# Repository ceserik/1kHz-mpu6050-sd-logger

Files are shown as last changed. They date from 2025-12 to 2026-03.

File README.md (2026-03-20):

# 1khz logger for mpu6050 accelerometer + gyro, using arduino mini pro

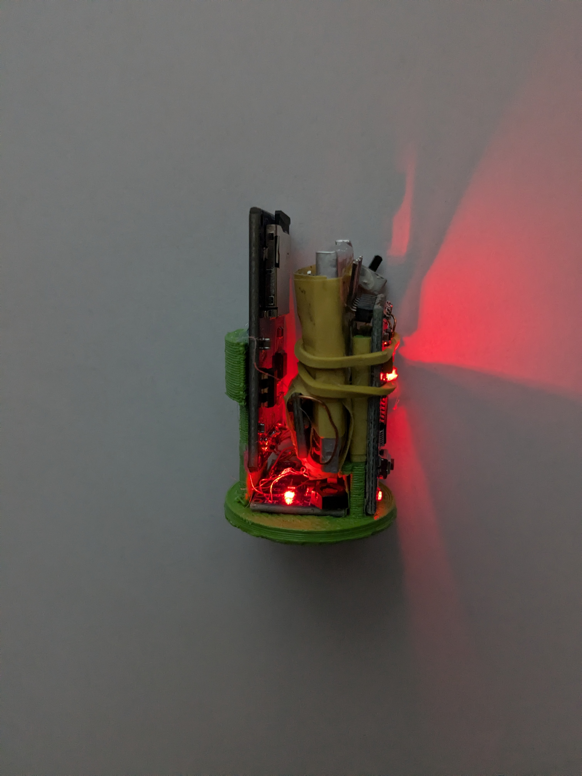
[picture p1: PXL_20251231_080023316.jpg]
Rocket Logger Device


I wrote this to log motion of hobby rocket launch. The code periodically reads FIFO buffer on MPU6050 and logs it to a SD card. Maximum sample rate of accelerometer is 1kHz, so I chose this as logging frequency. The data is stored as binary on sd card and you need to use converter.py to convert it to csv.

## Images

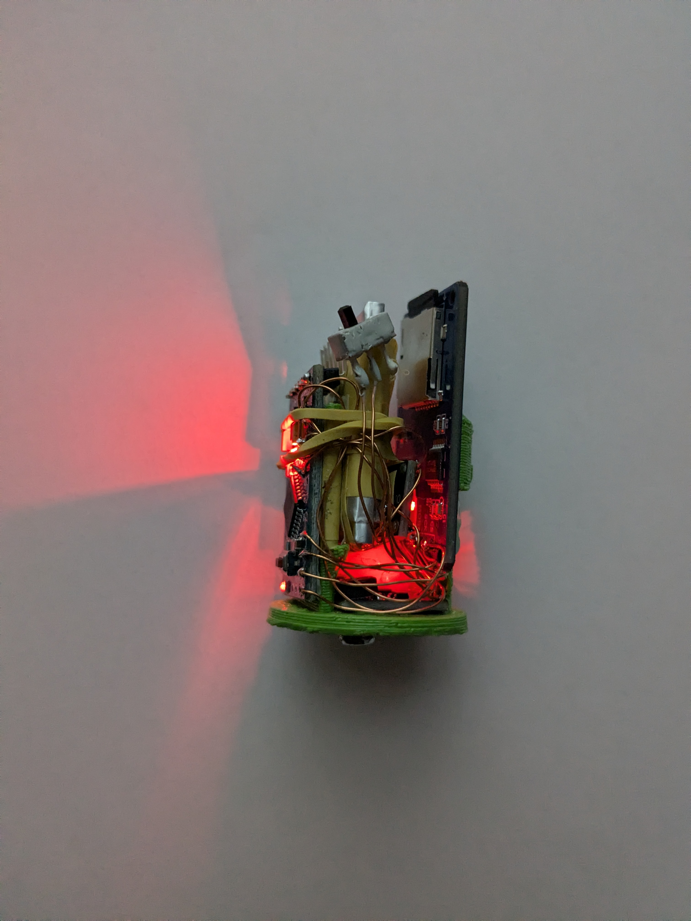
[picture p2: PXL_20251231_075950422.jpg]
Device View 1

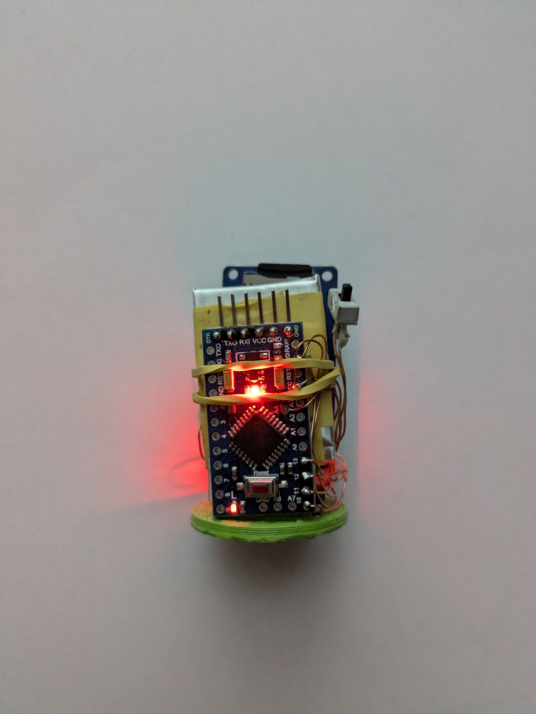
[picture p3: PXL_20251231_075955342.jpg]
Device View 2


## Data Analysis

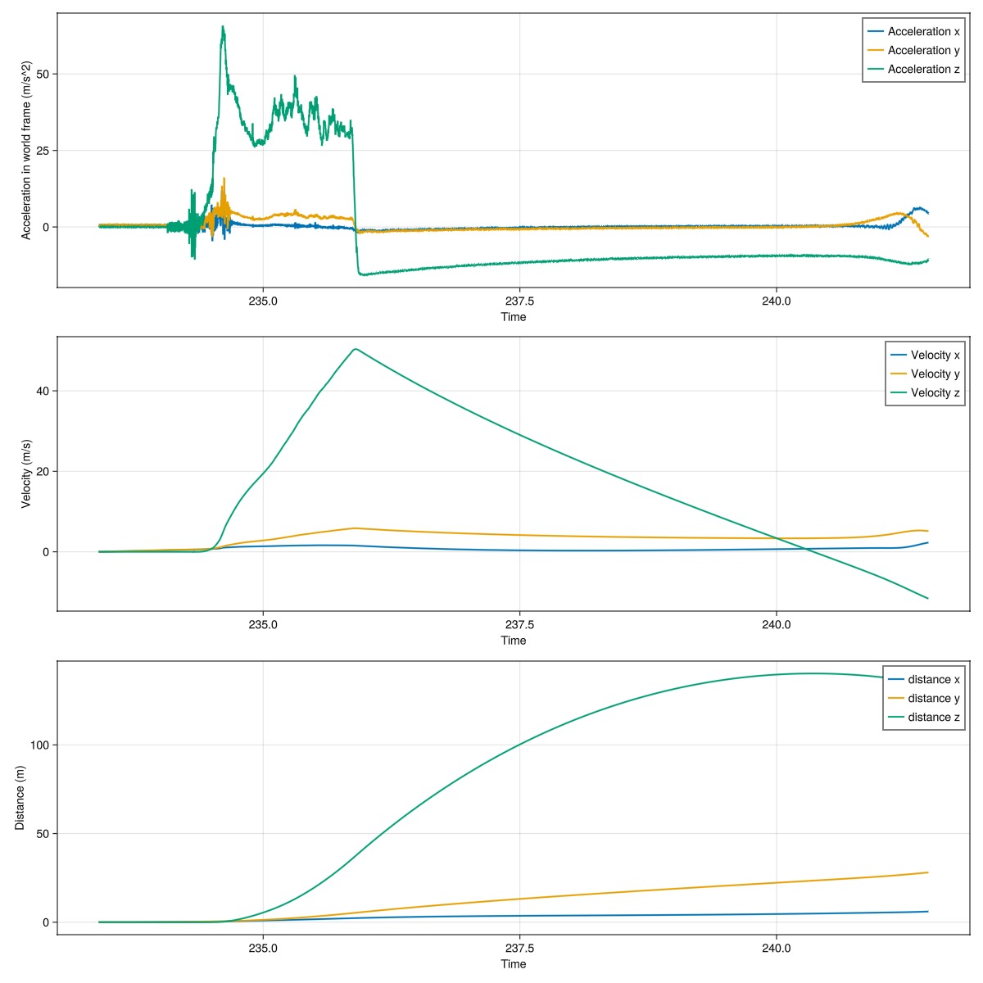
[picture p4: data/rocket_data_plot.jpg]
Rocket Data Plot


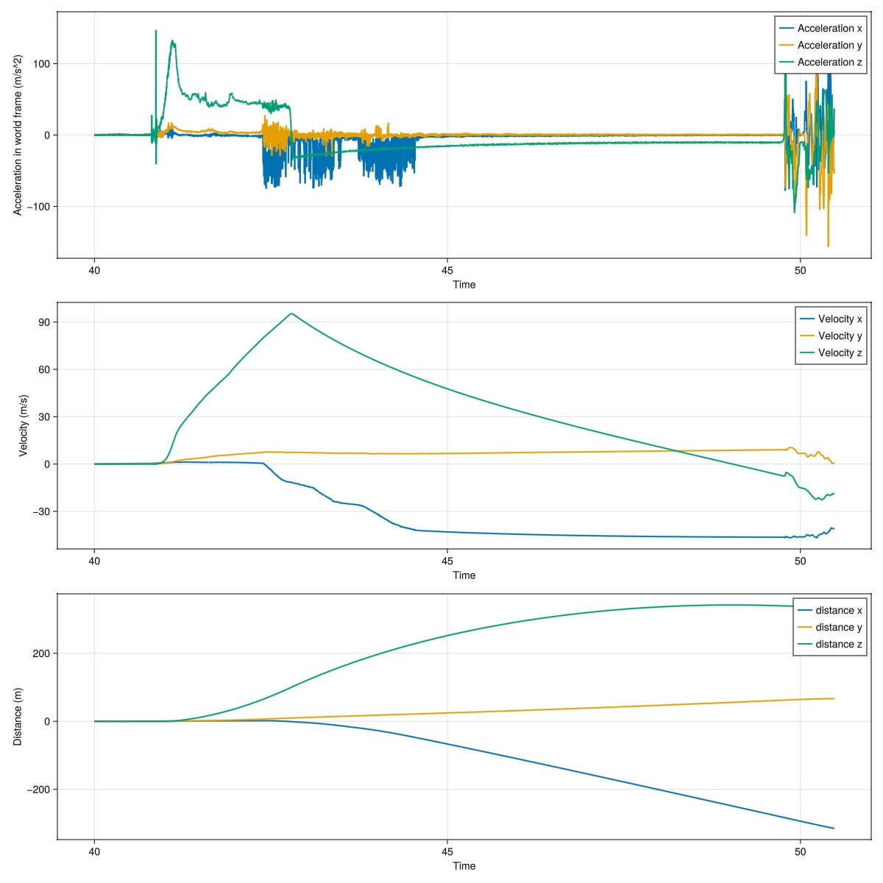
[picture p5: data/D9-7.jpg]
D9-7 Motor


## Parts list

- 5V/16MHz Arduino mini pro 
- 5V compatible SD adapter 
- MPU6050 
- 300mAh lipo (lasts for around 6 hours, which is overkill) 
- lipo protection/charging module
- 5V stepup 
- 3d printed holder(Freecad + .stp files in repo)

## How to use
1. Wire everyting up
2. Insert sd card
3. Power on
4. Wait for the calibration of accelerometer and gyros, the MPU6060 should be perfecly still and level with ground (Z axis of MPU6050 pointing directly up) 
5. Led on arduino should start blining fsat and that indicates logging
6. The file size pre allocated on sd card is 9.5MB which is enough for around 10 minutes of logging, after that more size is automatically allocated but it may cause overflow, i havent checked.
7. Power of
8. Remove sd card and put it into pc
9. use converter.py to convert binary to csv
10.???

## limitations
You have to use max 2GB sd card formatted as fat16. Larger sd cards will result in FIFO overflow around every 20 seconds, for about 60 milliseconds. This  should be fixable by better utilisation of SDfat library.

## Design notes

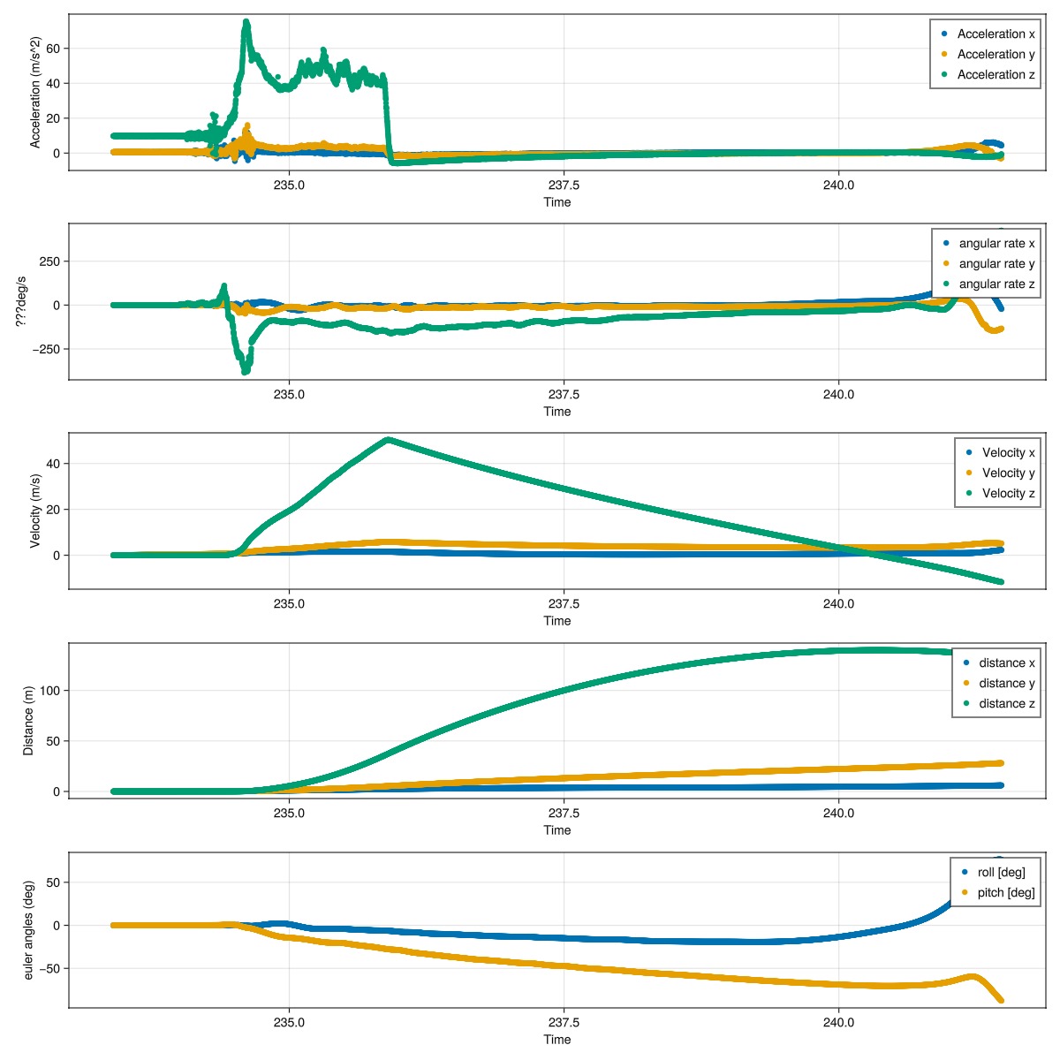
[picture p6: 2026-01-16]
rocket_data_plot.jpg

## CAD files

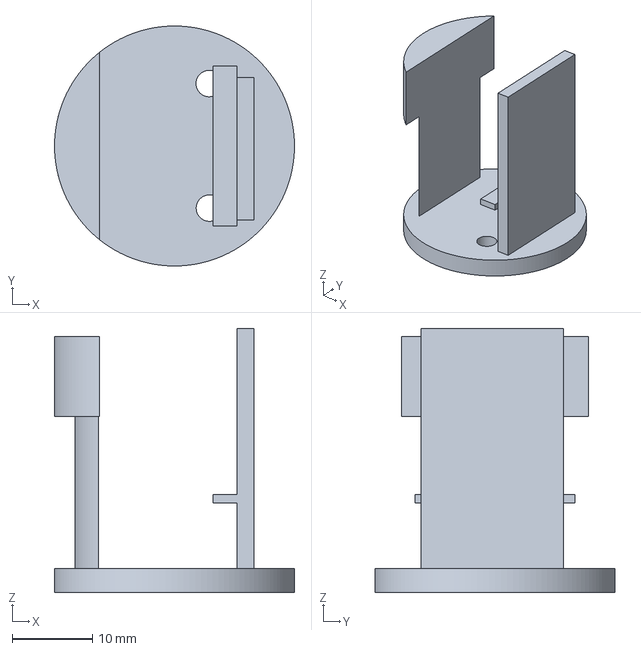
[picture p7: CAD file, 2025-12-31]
case-AssemblyCase.3mf
30.0 x 30.0 x 33.0 mm

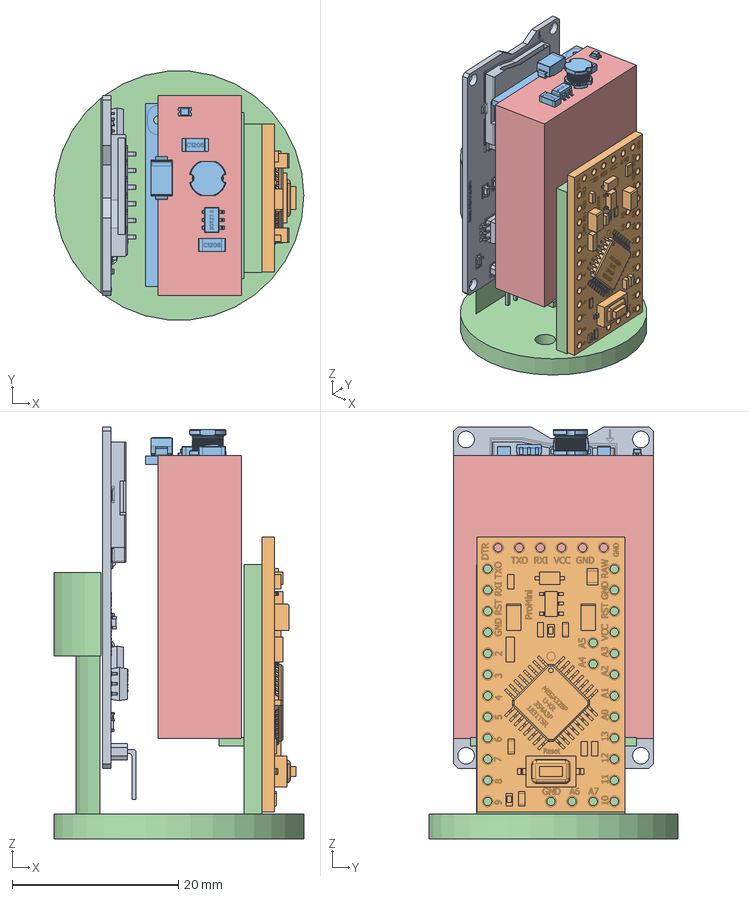
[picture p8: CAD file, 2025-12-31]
case.FCStd
30.0 x 29.9 x 49.5 mm
SD
ProMini
mini_dc_dc001
Case
lipo

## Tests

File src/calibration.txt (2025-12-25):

// MPU6050 offset-finder, based on Jeff Rowberg's MPU6050_RAW
// 2016-10-19 by Robert R. Fenichel (bob@fenichel.net)

// I2C device class (I2Cdev) demonstration Arduino sketch for MPU6050 class
// 10/7/2011 by Jeff Rowberg <jeff@rowberg.net>
// Updates should (hopefully) always be available at https://github.com/jrowberg/i2cdevlib
//
// Changelog:
//      2019-07-11 - added PID offset generation at begninning Generates first offsets 
//                 - in @ 6 seconds and completes with 4 more sets @ 10 seconds
//                 - then continues with origional 2016 calibration code.
//      2016-11-25 - added delays to reduce sampling rate to ~200 Hz
//                   added temporizing printing during long computations
//      2016-10-25 - requires inequality (Low < Target, High > Target) during expansion
//                   dynamic speed change when closing in
//      2016-10-22 - cosmetic changes
//      2016-10-19 - initial release of IMU_Zero
//      2013-05-08 - added multiple output formats
//                 - added seamless Fastwire support
//      2011-10-07 - initial release of MPU6050_RAW

/* ============================================
I2Cdev device library code is placed under the MIT license
Copyright (c) 2011 Jeff Rowberg

Permission is hereby granted, free of charge, to any person obtaining a copy
of this software and associated documentation files (the "Software"), to deal
in the Software without restriction, including without limitation the rights
to use, copy, modify, merge, publish, distribute, sublicense, and/or sell
copies of the Software, and to permit persons to whom the Software is
furnished to do so, subject to the following conditions:

The above copyright notice and this permission notice shall be included in
all copies or substantial portions of the Software.

THE SOFTWARE IS PROVIDED "AS IS", WITHOUT WARRANTY OF ANY KIND, EXPRESS OR
IMPLIED, INCLUDING BUT NOT LIMITED TO THE WARRANTIES OF MERCHANTABILITY,
FITNESS FOR A PARTICULAR PURPOSE AND NONINFRINGEMENT. IN NO EVENT SHALL THE
AUTHORS OR COPYRIGHT HOLDERS BE LIABLE FOR ANY CLAIM, DAMAGES OR OTHER
LIABILITY, WHETHER IN AN ACTION OF CONTRACT, TORT OR OTHERWISE, ARISING FROM,
OUT OF OR IN CONNECTION WITH THE SOFTWARE OR THE USE OR OTHER DEALINGS IN
THE SOFTWARE.

  If an MPU6050 
      * is an ideal member of its tribe, 
      * is properly warmed up, 
      * is at rest in a neutral position, 
      * is in a location where the pull of gravity is exactly 1g, and 
      * has been loaded with the best possible offsets, 
then it will report 0 for all accelerations and displacements, except for 
Z acceleration, for which it will report 16384 (that is, 2^14).  Your device 
probably won't do quite this well, but good offsets will all get the baseline 
outputs close to these target values.

  Put the MPU6050 on a flat and horizontal surface, and leave it operating for 
5-10 minutes so its temperature gets stabilized.

  Run this program.  A "----- done -----" line will indicate that it has done its best.
With the current accuracy-related constants (NFast = 1000, NSlow = 10000), it will take 
a few minutes to get there.

  Along the way, it will generate a dozen or so lines of output, showing that for each 
of the 6 desired offsets, it is 
      * first, trying to find two estimates, one too low and one too high, and
      * then, closing in until the bracket can't be made smaller.

  The line just above the "done" line will look something like
    [567,567] --> [-1,2]  [-2223,-2223] --> [0,1] [1131,1132] --> [16374,16404] [155,156] --> [-1,1]  [-25,-24] --> [0,3] [5,6] --> [0,4]
As will have been shown in interspersed header lines, the six groups making up this
line describe the optimum offsets for the X acceleration, Y acceleration, Z acceleration,
X gyro, Y gyro, and Z gyro, respectively.  In the sample shown just above, the trial showed
that +567 was the best offset for the X acceleration, -2223 was best for Y acceleration, 
and so on.

  The need for the delay between readings (usDelay) was brought to my attention by Nikolaus Doppelhammer.
===============================================
*/

// I2Cdev and MPU6050 must be installed as libraries, or else the .cpp/.h files
// for both classes must be in the include path of your project
//#include "Arduino.h"
#include "I2Cdev.h"
#include "MPU6050.h"

// Arduino Wire library is required if I2Cdev I2CDEV_ARDUINO_WIRE implementation
// is used in I2Cdev.h
#if I2CDEV_IMPLEMENTATION == I2CDEV_ARDUINO_WIRE
    #include "Wire.h"
#endif

// class default I2C address is 0x68
// specific I2C addresses may be passed as a parameter here
// AD0 low = 0x68 (default for InvenSense evaluation board)
// AD0 high = 0x69
MPU6050 accelgyro;
//MPU6050 accelgyro(0x69); // <-- use for AD0 high

const char LBRACKET = '[';
const char RBRACKET = ']';
const char COMMA    = ',';
const char BLANK    = ' ';
const char PERIOD   = '.';

const int iAx = 0;
const int iAy = 1;
const int iAz = 2;
const int iGx = 3;
const int iGy = 4;
const int iGz = 5;

const int usDelay = 3150;   // empirical, to hold sampling to 200 Hz
const int NFast =  1000;    // the bigger, the better (but slower)
const int NSlow = 10000;    // ..
const int LinesBetweenHeaders = 5;
      int LowValue[6];
      int HighValue[6];
      int Smoothed[6];
      int LowOffset[6];
      int HighOffset[6];
      int Target[6];
      int LinesOut;
      int N;
      
void ForceHeader()
  { LinesOut = 99; }
    
void GetSmoothed()
  { int16_t RawValue[6];
    int i;
    long Sums[6];
    for (i = iAx; i <= iGz; i++)
      { Sums[i] = 0; }
//    unsigned long Start = micros();

    for (i = 1; i <= N; i++)
      { // get sums
        accelgyro.getMotion6(&RawValue[iAx], &RawValue[iAy], &RawValue[iAz], 
                             &RawValue[iGx], &RawValue[iGy], &RawValue[iGz]);
        if ((i % 500) == 0)
          Serial.print(PERIOD);
        delayMicroseconds(usDelay);
        for (int j = iAx; j <= iGz; j++)
          Sums[j] = Sums[j] + RawValue[j];
      } // get sums
//    unsigned long usForN = micros() - Start;
//    Serial.print(" reading at ");
//    Serial.print(1000000/((usForN+N/2)/N));
//    Serial.println(" Hz");
    for (i = iAx; i <= iGz; i++)
      { Smoothed[i] = (Sums[i] + N/2) / N ; }
  } // GetSmoothed

void Initialize()
  {
    // join I2C bus (I2Cdev library doesn't do this automatically)
    #if I2CDEV_IMPLEMENTATION == I2CDEV_ARDUINO_WIRE
        Wire.begin();
    #elif I2CDEV_IMPLEMENTATION == I2CDEV_BUILTIN_FASTWIRE
        Fastwire::setup(400, true);
    #endif

    Serial.begin(9600);

    // initialize device
    Serial.println("Initializing I2C devices...");
    accelgyro.initialize();

    // verify connection
    Serial.println("Testing device connections...");
    Serial.println(accelgyro.testConnection() ? "MPU6050 connection successful" : "MPU6050 connection failed");
    Serial.println("PID tuning Each Dot = 100 readings");
  /*A tidbit on how PID (PI actually) tuning works. 
    When we change the offset in the MPU6050 we can get instant results. This allows us to use Proportional and 
    integral of the PID to discover the ideal offsets. Integral is the key to discovering these offsets, Integral 
    uses the error from set-point (set-point is zero), it takes a fraction of this error (error * ki) and adds it 
    to the integral value. Each reading narrows the error down to the desired offset. The greater the error from 
    set-point, the more we adjust the integral value. The proportional does its part by hiding the noise from the 
    integral math. The Derivative is not used because of the noise and because the sensor is stationary. With the 
    noise removed the integral value lands on a solid offset after just 600 readings. At the end of each set of 100 
    readings, the integral value is used for the actual offsets and the last proportional reading is ignored due to 
    the fact it reacts to any noise.
  */
        accelgyro.CalibrateAccel(6);
        accelgyro.CalibrateGyro(6);
        Serial.println("\nat 600 Readings");
        accelgyro.PrintActiveOffsets();
        Serial.println();
        accelgyro.CalibrateAccel(1);
        accelgyro.CalibrateGyro(1);
        Serial.println("700 Total Readings");
        accelgyro.PrintActiveOffsets();
        Serial.println();
        accelgyro.CalibrateAccel(1);
        accelgyro.CalibrateGyro(1);
        Serial.println("800 Total Readings");
        accelgyro.PrintActiveOffsets();
        Serial.println();
        accelgyro.CalibrateAccel(1);
        accelgyro.CalibrateGyro(1);
        Serial.println("900 Total Readings");
        accelgyro.PrintActiveOffsets();
        Serial.println();    
        accelgyro.CalibrateAccel(1);
        accelgyro.CalibrateGyro(1);
        Serial.println("1000 Total Readings");
        accelgyro.PrintActiveOffsets();
     Serial.println("\n\n Any of the above offsets will work nice \n\n Lets proof the PID tuning using another method:"); 
  } // Initialize

void SetOffsets(int TheOffsets[6])
  { accelgyro.setXAccelOffset(TheOffsets [iAx]);
    accelgyro.setYAccelOffset(TheOffsets [iAy]);
    accelgyro.setZAccelOffset(TheOffsets [iAz]);
    accelgyro.setXGyroOffset (TheOffsets [iGx]);
    accelgyro.setYGyroOffset (TheOffsets [iGy]);
    accelgyro.setZGyroOffset (TheOffsets [iGz]);
  } // SetOffsets

void ShowProgress()
  { if (LinesOut >= LinesBetweenHeaders)
      { // show header
        Serial.println("\tXAccel\t\t\tYAccel\t\t\t\tZAccel\t\t\tXGyro\t\t\tYGyro\t\t\tZGyro");
        LinesOut = 0;
      } // show header
    Serial.print(BLANK);
    for (int i = iAx; i <= iGz; i++)
      { Serial.print(LBRACKET);
        Serial.print(LowOffset[i]),
        Serial.print(COMMA);
        Serial.print(HighOffset[i]);
        Serial.print("] --> [");
        Serial.print(LowValue[i]);
        Serial.print(COMMA);
        Serial.print(HighValue[i]);
        if (i == iGz)
          { Serial.println(RBRACKET); }
        else
          { Serial.print("]\t"); }
      }
    LinesOut++;
  } // ShowProgress

// Forward declaration to allow use before definition
void SetAveraging(int NewN);

void PullBracketsIn()
  { boolean AllBracketsNarrow;
    boolean StillWorking;
    int NewOffset[6];
  
    Serial.println("\nclosing in:");
    AllBracketsNarrow = false;
    ForceHeader();
    StillWorking = true;
    while (StillWorking) 
      { StillWorking = false;
        if (AllBracketsNarrow && (N == NFast))
          { SetAveraging(NSlow); }
        else
          { AllBracketsNarrow = true; }// tentative
        for (int i = iAx; i <= iGz; i++)
          { if (HighOffset[i] <= (LowOffset[i]+1))
              { NewOffset[i] = LowOffset[i]; }
            else
              { // binary search
                StillWorking = true;
                NewOffset[i] = (LowOffset[i] + HighOffset[i]) / 2;
                if (HighOffset[i] > (LowOffset[i] + 10))
                  { AllBracketsNarrow = false; }
              } // binary search
          }
        SetOffsets(NewOffset);
        GetSmoothed();
        for (int i = iAx; i <= iGz; i++)
          { // closing in
            if (Smoothed[i] > Target[i])
              { // use lower half
                HighOffset[i] = NewOffset[i];
                HighValue[i] = Smoothed[i];
              } // use lower half
            else
              { // use upper half
                LowOffset[i] = NewOffset[i];
                LowValue[i] = Smoothed[i];
              } // use upper half
          } // closing in
        ShowProgress();
      } // still working
   
  } // PullBracketsIn

void PullBracketsOut()
  { boolean Done = false;
    int NextLowOffset[6];
    int NextHighOffset[6];

    Serial.println("expanding:");
    ForceHeader();
 
    while (!Done)
      { Done = true;
        SetOffsets(LowOffset);
        GetSmoothed();
        for (int i = iAx; i <= iGz; i++)
          { // got low values
            LowValue[i] = Smoothed[i];
            if (LowValue[i] >= Target[i])
              { Done = false;
                NextLowOffset[i] = LowOffset[i] - 1000;
              }
            else
              { NextLowOffset[i] = LowOffset[i]; }
          } // got low values
      
        SetOffsets(HighOffset);
        GetSmoothed();
        for (int i = iAx; i <= iGz; i++)
          { // got high values
            HighValue[i] = Smoothed[i];
            if (HighValue[i] <= Target[i])
              { Done = false;
                NextHighOffset[i] = HighOffset[i] + 1000;
              }
            else
              { NextHighOffset[i] = HighOffset[i]; }
          } // got high values
        ShowProgress();
        for (int i = iAx; i <= iGz; i++)
          { LowOffset[i] = NextLowOffset[i];   // had to wait until ShowProgress done
            HighOffset[i] = NextHighOffset[i]; // ..
          }
     } // keep going
  } // PullBracketsOut

void SetAveraging(int NewN)
  { N = NewN;
    Serial.print("averaging ");
    Serial.print(N);
    Serial.println(" readings each time");
   } // SetAveraging

void setup()
  { Initialize();
    for (int i = iAx; i <= iGz; i++)
      { // set targets and initial guesses
        Target[i] = 0; // must fix for ZAccel 
        HighOffset[i] = 0;
        LowOffset[i] = 0;
      } // set targets and initial guesses
    Target[iAz] = 16384;
    SetAveraging(NFast);
    
    PullBracketsOut();
    PullBracketsIn();
    
    Serial.println("-------------- done --------------");
  } // setup
 
void loop()
  {
  } // loop

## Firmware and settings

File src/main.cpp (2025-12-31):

// WIRING 
// MPU6050
// SCL - A5
// SDA - A4
//
// SD READER
// CS - 10
// SCK -13
// MOSI-11
// MISO-12 



#define SPI_CLOCK SD_SCK_MHZ(50)
#define SD_CS_PIN SS
#define SD_CONFIG SdSpiConfig(SD_CS_PIN, DEDICATED_SPI, SPI_CLOCK)
#define LOG_INTERVAL_USEC 600
#define MAX_FILE_SIZE 10000000UL // is about 104 minutes of logging
#define BUFFER_SIZE 168  // 7 samples * 16 bytes (4 timestamp + 12 IMU) per chunk


//#define UTF8_SD
#define DEBUG

#include "Arduino.h"
#include "I2Cdev.h"
#include "MPU6050.h"
//#include <SD.h>
#include "SdFat.h"

// Arduino Wire library is required if I2Cdev I2CDEV_ARDUINO_WIRE implementation
// is used in I2Cdev.h
#if I2CDEV_IMPLEMENTATION == I2CDEV_ARDUINO_WIRE
    #include "Wire.h"
#endif

class DummySerial : public Stream
{
private:
	int peek_buffer;
public:
	DummySerial() { peek_buffer = -1; };
	void begin(unsigned long) {};
	void begin(unsigned long, uint8_t){};
	void end(void){};

	virtual int available(void){return 0;};
	virtual int peek(void){return 0;};
	virtual int read(void){return 0;};
	virtual int availableForWrite(void){return 0;};
	virtual void flush(void){};
	virtual size_t write(uint8_t){return 0;};
	virtual size_t write(const uint8_t*, size_t){return 0;};
	using Print::write; // pull in write(str) and write(buf, size) from Print
	operator bool();
	uint32_t baud(){return 0;};
	uint8_t stopbits(){return 0;};
	uint8_t paritytype(){return 0;};
	uint8_t numbits(){return 0;};
	bool dtr(){return 0;};
	bool rts(){return 0;};
	enum {
		ONE_STOP_BIT = 0,
		ONE_AND_HALF_STOP_BIT = 1,
		TWO_STOP_BITS = 2,
	};
	enum {
		NO_PARITY = 0,
		ODD_PARITY = 1,
		EVEN_PARITY = 2,
		MARK_PARITY = 3,
		SPACE_PARITY = 4,
	};

};

DummySerial dummySerial;

#ifdef DEBUG
#define mySerial Serial
#else
#define mySerial dummySerial
#endif

MPU6050 accelgyro;
int16_t ax, ay, az;
int16_t gx, gy, gz;

const int chipSelect = 10;
SdFs sd;
FsFile file;
#define LED_PIN 13
bool blinkState = false;

uint8_t counter = 0;
uint16_t fileNum = 0;
uint16_t syncCounter = 0;
unsigned long start;
void openNewFile() {
  if (file.isOpen()) {
    file.close();
  }

  char filename[10];
  // Find first non-existent file number
  while (fileNum < 100) {
    sprintf(filename, "%02d.bin", fileNum);
    if (!sd.exists(filename)) {
      break;  // Found available filename
    }
    fileNum++;
  }
  
  file = sd.open(filename, O_RDWR | O_CREAT | O_EXCL);
  if (!file) {
    while (1);  // Halt on error
  }

  if (!file.preAllocate(MAX_FILE_SIZE)) {
    file.close();
    while (1);
  }
  
  fileNum++;  // Ready for next file
}

void setup() {
    // join I2C bus (I2Cdev library doesn't do this automatically)
    #if I2CDEV_IMPLEMENTATION == I2CDEV_ARDUINO_WIRE
        Wire.begin();
        Wire.setClock(400000);
    #elif I2CDEV_IMPLEMENTATION == I2CDEV_BUILTIN_FASTWIRE
        Fastwire::setup(400, true);
    #endif
    mySerial.begin(115200);
    // initialize MPU6050
    //mySerial.println(F("Initializing I2C devices..."));
    accelgyro.initialize();
    accelgyro.setFullScaleAccelRange(MPU6050_ACCEL_FS_16);
    accelgyro.setFullScaleGyroRange(MPU6050_GYRO_FS_1000);
    accelgyro.setDLPFMode(0);  // 8kHz base rate for gyro
    // rate=0 -> 8000Hz, rate=1 -> 4000Hz, rate=3 -> 2000Hz, rate=7 -> 1000Hz
    accelgyro.setRate(7);  // 8kHz (but accel limited to 1kHz max)
    // setup MPU6050 FIFO
    accelgyro.setFIFOEnabled(1);
    accelgyro.setAccelFIFOEnabled(1);
    accelgyro.setXGyroFIFOEnabled(1);
    accelgyro.setYGyroFIFOEnabled(1);
    accelgyro.setZGyroFIFOEnabled(1);
    accelgyro.setTempFIFOEnabled(0);
    accelgyro.setSlave0FIFOEnabled(0);
    accelgyro.setSlave1FIFOEnabled(0);
    accelgyro.setSlave2FIFOEnabled(0);
    accelgyro.setSlave3FIFOEnabled(0);
    
    // verify connection
    //mySerial.println(F("Testing device connections..."));
    //mySerial.println(accelgyro.testConnection() ? F("MPU6050 connection successful") : F("MPU6050 connection failed"));

    // use the code below to change accel/gyro offset values
    
//    mySerial.println(F("Updating internal sensor offsets..."));
    // -76	-2359	1688	0	0	0
    mySerial.print(F("\n"));
    accelgyro.setXGyroOffset(97);
    accelgyro.setYGyroOffset(112);
    accelgyro.setZGyroOffset(-22);

    accelgyro.setXAccelOffset(-1911);  // Test with no offsets
    accelgyro.setYAccelOffset(-553);
    accelgyro.setZAccelOffset(1433);
    mySerial.println("stay still calibrating");
    delay(1000);
    accelgyro.CalibrateAccel(10);
    mySerial.println("calibrating gyro");
    accelgyro.CalibrateGyro(10);
    mySerial.println("calibation finished");
    Serial.println("\nat 600 Readings");
    //accelgyro.PrintActiveOffsets();

    mySerial.print(accelgyro.getXAccelOffset()); mySerial.print(F("\t")); // -76
    mySerial.print(accelgyro.getYAccelOffset()); mySerial.print(F("\t")); // -2359
    mySerial.print(accelgyro.getZAccelOffset()); mySerial.print(F("\t")); // 1688
    mySerial.print(accelgyro.getXGyroOffset()); mySerial.print(F("\t")); // 0
    mySerial.print(accelgyro.getYGyroOffset()); mySerial.print(F("\t")); // 0
    mySerial.print(accelgyro.getZGyroOffset()); mySerial.print(F("\t")); // 0
    mySerial.print(F("\n"));
    
    // Debug: Check actual range settings
    mySerial.print(F("Accel range: "));
    mySerial.println(accelgyro.getFullScaleAccelRange());  // Should be 0 for ±2g
    mySerial.print(F("Gyro range: "));
    mySerial.println(accelgyro.getFullScaleGyroRange());  // Should be 0 for ±250°/s

    mySerial.println(F("Initializing SD card..."));

    // Reset CS pin to ensure clean state
    pinMode(SD_CS_PIN, OUTPUT);
    digitalWrite(SD_CS_PIN, HIGH);
    delay(10);
    
    // Try multiple times to initialize
    bool sdInitialized = false;
    for (int attempt = 0; attempt < 200; attempt++) {
      if (sd.begin(SD_CONFIG)) {
        sdInitialized = true;
        break;
      }
 //     mySerial.print(F("SD init attempt "));
      mySerial.print(attempt + 1);
      mySerial.println(F(" failed, retrying..."));
      sd.end();
      delay(1000);
    }
    
    if (!sdInitialized) {
      mySerial.println(F("FF"));
      while (true);
    }
  
    openNewFile();
    
 //   Serial.println(F("initialization done."));
    pinMode(LED_PIN, OUTPUT);
    accelgyro.resetFIFO();
    mySerial.println(F("logging"));
    start = millis();
}

void loop() {
    uint16_t fifoCount = accelgyro.getFIFOCount();
    
    // Check for FIFO overflow (max is 1024 bytes)
    if (fifoCount >= 1024) {
      mySerial.println(F("FIFO overflow - resetting"));
      accelgyro.resetFIFO();
      return;
    }
    
    // Read IMU data and add timestamps (16 bytes per sample: 4 timestamp + 12 IMU)
    if (fifoCount >= BUFFER_SIZE && millis() ) {  // 14 samples * 12 bytes - start < 10000
      //mySerial.println(accelgyro.getFIFOCount());
      
      char imuData[BUFFER_SIZE];  // 14 samples of raw IMU data
      char outputData[224];  // 14 samples with timestamps (14 * 16)
      
      // Read IMU data in two chunks, for some reason reading more than 128 bytes at once results in mangled data
      accelgyro.getFIFOBytes((uint8_t*)imuData, 84);  // 7 samples
      accelgyro.getFIFOBytes((uint8_t*)imuData + 84, 84);  // 7 more samples
      
      // Interpolate timestamps for each sample
      // Sample rate = 1000 Hz (1 ms per sample) from setRate(7) with DLPF=0
      unsigned long currentTime = millis()-start;
      for (int i = 0; i < 14; i++) {
        // Interpolate: oldest sample first, newest sample last
        // Sample 0 was captured 13 ms ago, sample 13 was just captured
        unsigned long timestamp = currentTime - (13 - i);
        
        // Write timestamp (4 bytes, big-endian)
        outputData[i * 16 + 0] = (timestamp >> 24) & 0xFF;
        outputData[i * 16 + 1] = (timestamp >> 16) & 0xFF;
        outputData[i * 16 + 2] = (timestamp >> 8) & 0xFF;
        outputData[i * 16 + 3] = timestamp & 0xFF;
        // Copy IMU data (12 bytes)
        memcpy(&outputData[i * 16 + 4], &imuData[i * 12], 12);
      }
      
      file.write(outputData, 224);
      //mySerial.println(accelgyro.getFIFOCount());
      
      // Only sync every 10 writes to reduce SD overhead
      syncCounter++;
      if (syncCounter >= 20) {
        file.sync();
        syncCounter = 0;
      }
    }
    
    // blink LED to indicate activity
    blinkState = !blinkState;
    digitalWrite(LED_PIN, blinkState);
}

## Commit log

2025-12-25 added calibration
2025-12-25 removed SD card bug
    [main.cpp]
2025-12-27 added gyros
2025-12-28 added automatic calibration on powerup
2025-12-31 added wiring
2025-12-31 Added case and better readme
    [case-AssemblyCase.3mf, case.FCStd]
2026-01-16 added actual rocket launch binary data
    [raketa3.csv]
2026-03-20 added data from Klima D9-7 motor
    [motor_D9-7_start_1.csv]
